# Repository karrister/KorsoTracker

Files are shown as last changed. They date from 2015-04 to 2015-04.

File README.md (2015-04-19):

YAAT, an APRS Tracker
=============

This project is the HW design (PCB) for a ham radio APRS tracker. It takes input from GPS through UART, parsing the NMEA packets with location and speed info, making them into AX.25 frames and then converting that to physical layer data (analogic sound - at 1200 and 2200 khz).

There are many different APRS devices described on the internet but none of them were quite what I wanted. And afterall, ham radio is all about making your own devices!

73
OH2FLI

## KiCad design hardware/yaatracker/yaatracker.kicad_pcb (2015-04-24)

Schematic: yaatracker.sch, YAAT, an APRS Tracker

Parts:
C1, C2: 15pF
C3, C7: 0uF1
C4, C8: tbd
C5, C11, C12: 4uF7
C6: CSMALL
C9: 1uF
C10: 270nF
D1, D2: LED
D3: DIODE
D4: DIODESCH
D5: LED tbd
J1: USB_MINI
P1: TP_URX
P2: GPIO10_GND_JUMPER
P3: TP_UTX
P4: TON2
P5: RESET_CONN_2
P6: UART_TX_JUMPER
P7: MBUTTON3
P8: TP_TON1
P9: MBUTTON1
P10: BATT
P11: MBUTTON2
P12: ICSP_CONN5
P13: I2C_SCREEN
P14: R_VCC
P15: GPS_DE9
P16: RADIO_DE9
P17: SW5
Q1: DMP1045U
R1, R2: 60
R3, R12, R15: 4k7
R4, R6, R16, R17: 1k
R5, R7, R13, R14, R19: tbd
R8, R11: JUMPER
R9: 47k
R10: 100K
R18: 2k
RV1, RV2: 10k
T1: BSV52
U1: TPS769XX
U2: TLV271
U3: PIC18F14K50
U4: MCP7383X
X1: 10MHz

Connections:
+3.3V: C5.1, C6.2, C8.1, P7.2 (PM), P9.2 (PM), P11.2 (PM), P12.2, P13.1, P15.1, P17.2 (PM), R1.1, R2.1, R3.1, R12.2, R15.2, RV1.1, U1.5 (OUT), U2.5 (Vdd), U3.1 (Vdd)
/AUDIO_IN: C3.2, P16.2
/AUDIO_OUT: P4.1, P16.3, RV2.2
/PTT: P16.1, T1.3 (C)
/R_VOUT: P14.2 (PM), P16.5
/UART_RX: P1.1, P15.4, U3.12 (RB5/AN11/RX)
/UART_TX: P3.1, P6.2 (PM), P15.3
GND: C1.1, C2.1, C4.2, C5.2, C6.1, C7.2, C8.2, C9.2, C10.1, C11.2, C12.2, J1.5 (GND), P2.1, P5.1, P10.2 (PM), P12.3, P13.2, P15.2, P16.4, R6.1, R10.2, R16.1, R17.1, R18.1, RV1.3, RV2.3, T1.2 (E), U1.2 (GND), U1.3 (EN), U2.2 (GND), U3.20 (Vss), U4.2 (Vss)
unnamed: D1.1 (A), R1.2
unnamed: D2.1 (A), R2.2
unnamed: D3.1 (A), R3.2
unnamed: C4.1, R5.1, RV2.1
unnamed: D1.2 (K), U3.6 (RC4/P1B)
unnamed: D3.2 (K), P5.2 (PM), P12.1, U3.4 (RA3/MCLR)
unnamed: R9.1, U3.8 (RC6/AN8/SS)
unnamed: P11.1, R14.2, R17.2
unnamed: P9.1, R13.2, R16.2
unnamed: R7.1, U3.7 (RC3/AN7)
unnamed: C7.1, R9.2, T1.1 (B)
unnamed: D2.2 (K), U3.5 (RC5/CCP1)
unnamed: P7.1, R4.1
unnamed: P2.2 (PM), P6.1, R4.2, U3.10 (RB7/TX)
unnamed: R14.1, U3.15 (RC1/AN5/INT1)
unnamed: R13.1, U3.16 (RC0/AN4/INT0)
unnamed: C3.1, RV1.2, U3.9 (RC7/AN9/SDO)
unnamed: P17.1, R6.2, R7.2
unnamed: C10.2, U3.17 (VUSB)
unnamed: J1.3 (D+), P12.4, U3.19 (RA0/D+)
unnamed: J1.2 (D-), P12.5, U3.18 (RA1/D-)
unnamed: C9.1, D4.2 (K), Q1.S, U1.1 (IN)
unnamed: R11.1, U2.4 (-IN)
unnamed: R8.2, U2.1 (OUT)
unnamed: R5.2, R8.1, R11.2
unnamed: C11.1, P10.1, Q1.D, U4.3 (Vbat)
unnamed: R18.2, U4.5 (PROG)
unnamed: C2.2, U3.2 (RA5/OSC1), X1.2
unnamed: C1.2, U3.3 (RA4/OSC2), X1.1
unnamed: C12.1, D4.1 (A), J1.1 (VBUS), P14.1, Q1.G, R10.1, R19.2, U4.4 (Vdd)
unnamed: D5.2 (K), U4.1 (STAT)
unnamed: D5.1 (A), R19.1
unnamed: P13.3, R12.1, U3.11 (RB6/SCK)
unnamed: P13.4, R15.1, U3.13 (RB4/AN10/SDI/SDA)
unnamed: P8.1, U2.3 (+IN), U3.14 (RC2/AN6/INT2)

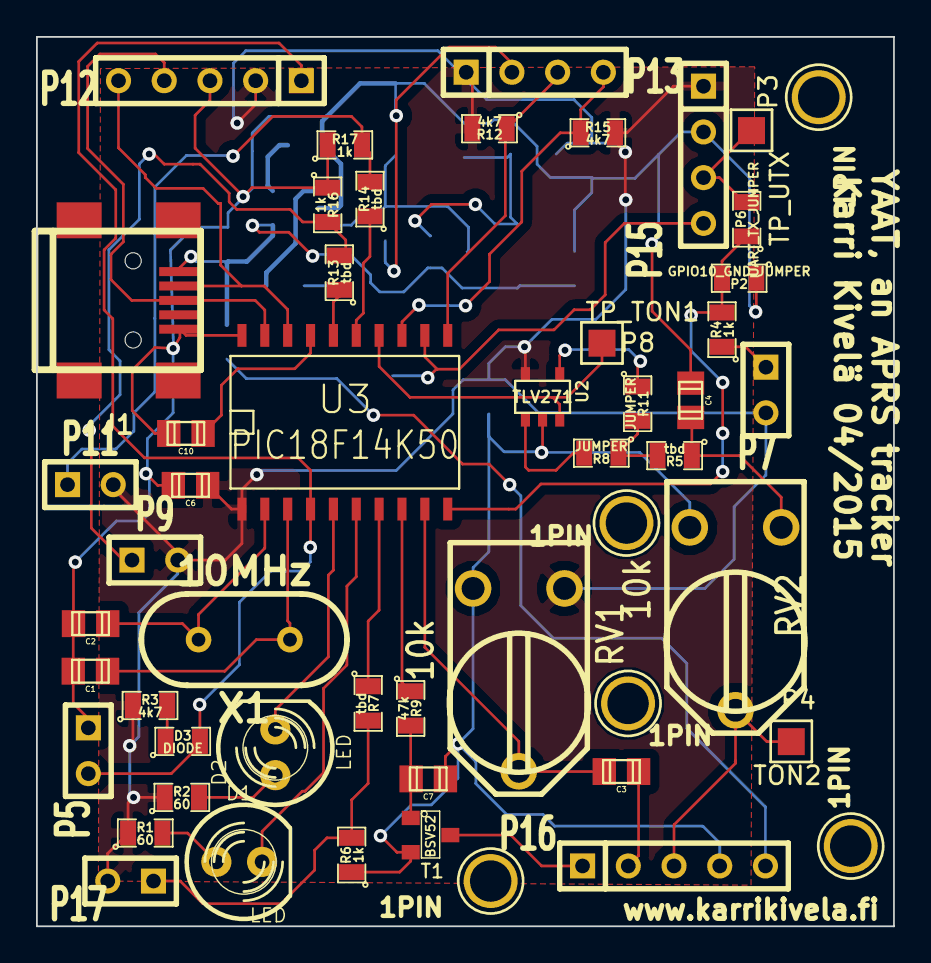
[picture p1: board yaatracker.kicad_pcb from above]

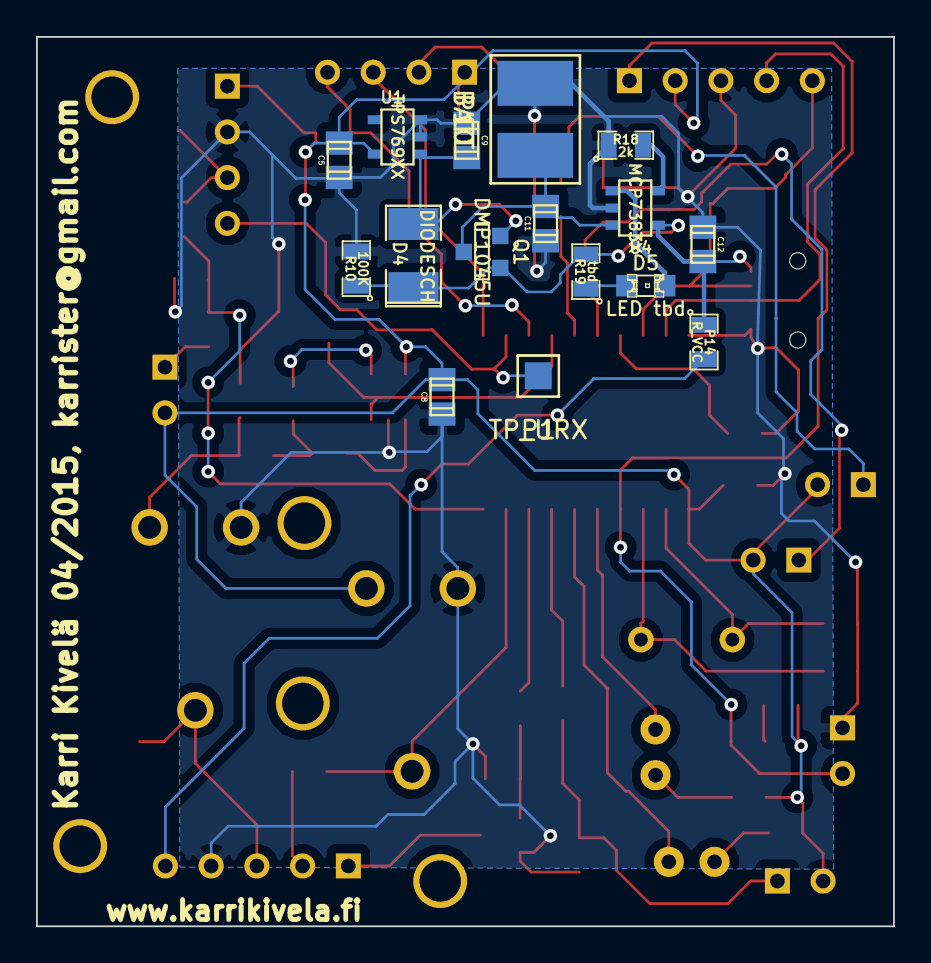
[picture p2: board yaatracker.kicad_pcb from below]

Board: 2 copper layers, 47.6 x 49.4 mm, 68 parts (16 on the bottom side), 43 nets.

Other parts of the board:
1PIN, 1PIN#2, 1PIN#3, 1PIN#4, 1PIN#5: P***; 1pin

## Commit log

2015-04-18 Initial commit
    Initial commit with the README file, and the kicad project file for the
    pcb design project.
2015-04-18 Schematics started
    Schematics started, power supply line ready. Committing library from my
    other BT project
    [$korsotracker.sch, korsotracker.sch]
2015-04-18 Schematics op amp
    Schematics drawing now with op amp to audio out
    [$korsotracker.sch, korsotracker.sch]
2015-04-18 Schematics + License
    Schematics support now ICSP connector.
    Also the license file added.
    [korsotracker.sch]
2015-04-18 More work on schematics
    Now supporting PIC oscillator, jumper line for UART TX and audio
    in/carrier detect.
    [korsotracker.sch]
2015-04-18 Schematics mostly done
    Schematics are only lacking 2 LEDs and all the buttons and a switch.
    Also need to revisit the USB connection.
    [korsotracker.sch]
2015-04-19 Renaming project
    [yaatracker.sch]
2015-04-19 Renaming project
    Continuing to rename project
    [yaatracker.sch]
2015-04-19 Restructuring directories
    [yaatracker.sch]
2015-04-19 Schematics before check
    Schematics are ready to be checked.
    [yaatracker.sch]
2015-04-19 Schematics work
    Working to get a good pcb
    [yaatracker.sch]
2015-04-20 SCHEMATICS DONE
    Schematics should be now ready.
    [yaatracker.sch]
2015-04-20 Schematics after ERC
    Some fixes after ERC. ERC still complains but only warnings - nothing
    serious that would need to be fixed for now.
    [yaatracker.sch]
2015-04-23 Netlist generated
    Netlist generated, footprints for parts chosen.
2015-04-24 PCB layout power circuit
    Started the power circuit layout of the PCB.
    [yaatracker.kicad_pcb, yaatracker.sch]
2015-04-24 PCB layout power circuit finished
    Layout of the power circuit is now finished
    [yaatracker.kicad_pcb, yaatracker.sch]
2015-04-24 More PCB layout
    ICSP connector done, as well as screen/I2C connector, and a few buttons.
    [yaatracker.kicad_pcb]
2015-04-24 Some more PCB layout
    Some more PCB layout. Forgot to connect two grounds together.
    [yaatracker.kicad_pcb]
2015-04-24 Traces to GPS conn, audio out
    Routed traces to GPS uart connector, and audio out done to pot.
    [$yaatracker.sch, yaatracker.kicad_pcb]
2015-04-24 PCB layout almost finished
    Lacking LEDs, and a few buttons to be routed.
    [yaatracker.kicad_pcb]
2015-04-24 PCB layout routing done
    PCB layout traces routing done, but need to add a button connected to pin 7 (pull down
    and current-limiting resistor already exist in design).
    [yaatracker.kicad_pcb]
2015-04-24 PCB layout last switch
    Added and routed another switch successfully.
    [$yaatracker.sch, yaatracker.kicad_pcb, yaatracker.sch]
2015-04-24 PCB in the last stage
    Layout done otherwise but need to see if can fix the "unconnected pad"
    error - for some reason USB connector shield wants to be connected to a
    data pin...
    [yaatracker.kicad_pcb]
2015-04-24 PCB design finished. Gerber files ready.
    PCB design is done, and gerber files have been generated.
    [yaatracker-B_Cu.gbl, yaatracker-B_Mask.gbs, yaatracker-B_SilkS.gbo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]
2015-04-24 PCB version 1.0
    PCB done, ready for printing. PCB version 1.0.
    [yaatracker.kicad_pcb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]
